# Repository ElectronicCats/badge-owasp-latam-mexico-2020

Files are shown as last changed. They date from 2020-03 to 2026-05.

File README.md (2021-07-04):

# Badge OWASP LATAM México 2020

Una vez mas en el año 2020 nos reunimos para celebrar OWASP Latam México 2020, en Electronic Cats hemos creado un badge electronico para todos los asistentes, bienvenidos a la #badgelive

## Capture The Flag

Unete al reto de Capture The Flag y descubre todo lo que tiene dentro este badge por medio de una herramienta Bluetooth ;)

## Tecnologia

- ESP32 BLE and WIFI
- Convetidor USB-Serial
- LED WS2812B Mini
- OLED
  - [Version 1](https://uelectronics.com/producto/display-pantalla-oled-blanco-128x32-0-91-i2c-ssd1306/)
  - [Version 2](https://articulo.mercadolibre.com.mx/MLM-878713326-display-pantalla-oled-128x32-091-arduino-pic-i2c-lcd-_JM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)

## Links

- [ESP32 con Arduino](https://github.com/espressif/arduino-esp32)
- [Herramienta para carga de binario CTF](https://github.com/espressif/esptool)

## Agradecimientos
¿Quieres dar las gracias? Etiqueta a estas empresas en redes sociales y muestrales tu badge, gracias a ellos es posible

- [PCBWay](https://www.pcbway.com/)
- [LCSC](https://lcsc.com/)
- [ESPRESSIF](https://www.espressif.com/)

## License

Electronic Cats invests time and resources providing this open source design, please support Electronic Cats and open-source hardware by purchasing products from Electronic Cats!

Designed by Electronic Cats.

Hardware released under an CERN Open Hardware Licence v1.2. See the LICENSE_HARDWARE file for more information.

Electronic Cats is a registered trademark, please do not use if you sell these PCBs.

Dec 2019

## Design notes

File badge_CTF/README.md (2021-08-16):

# OWASP Riviera Maya
### (Capture The Flag)

**Instalación en ESP32.**
**Linux**
./esptool.py -b 115200 --port /dev/ttyUSB0 --chip esp32 
   --before default_reset
   --after hard_reset  write_flash --flash_freq 80m 0x000000 ./badge_v1.1.bin

**Windows**
./esptool.py -b 115200 --port COM3 --chip esp32 
   --before default_reset
   --after hard_reset write_flash --flash_freq 80m 0x000000 ./badge_v1.1.bin

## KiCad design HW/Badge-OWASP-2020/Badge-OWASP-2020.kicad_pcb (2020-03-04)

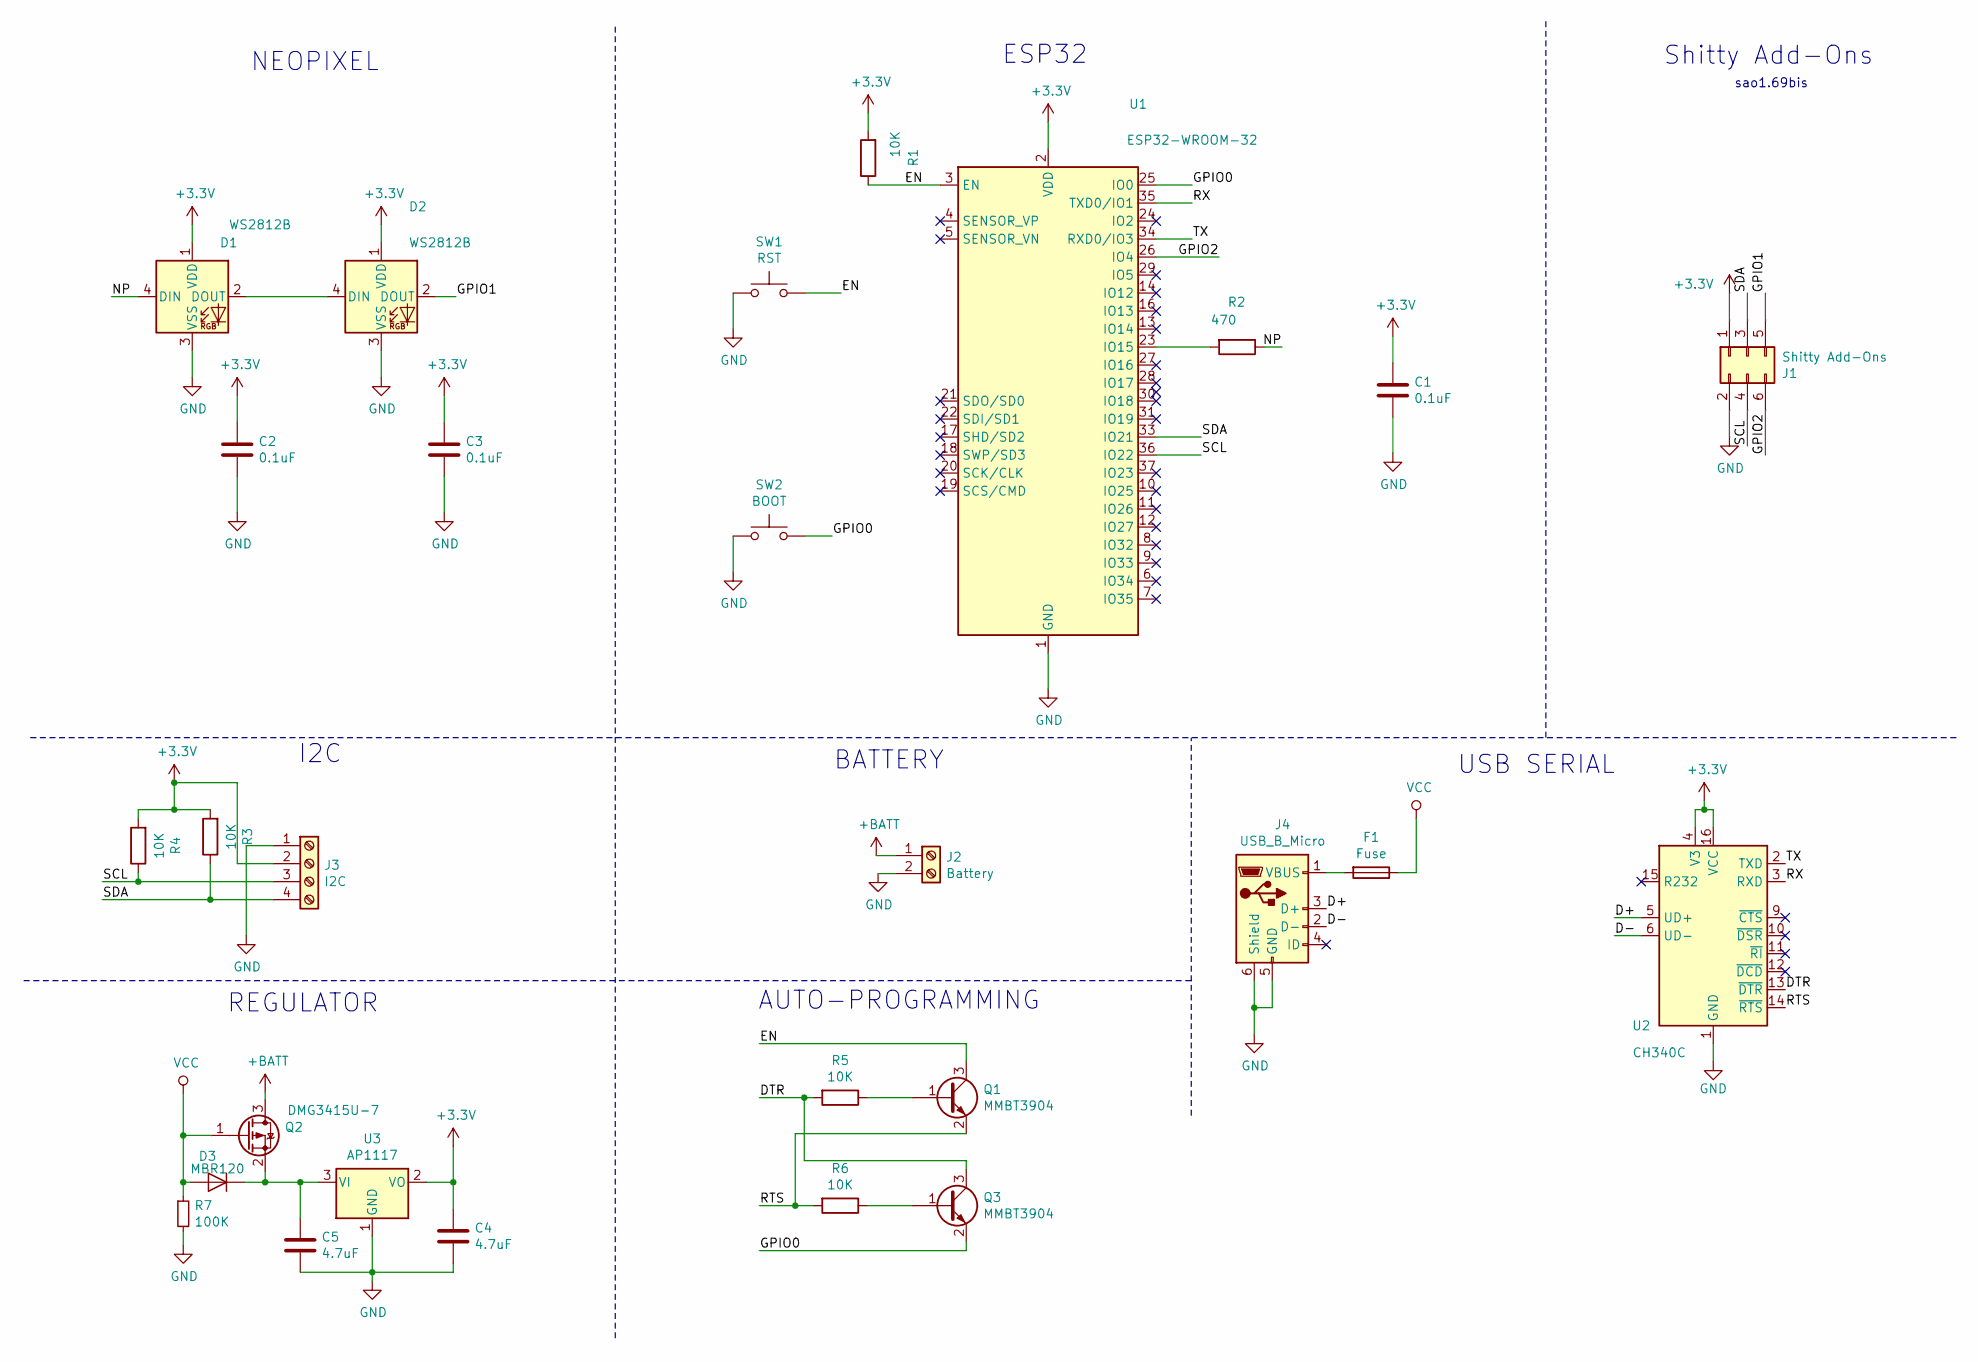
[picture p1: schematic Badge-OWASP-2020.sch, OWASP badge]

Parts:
C1, C2, C3: 0.1uF; C_0805_2012Metric_Pad1.15x1.40mm_HandSolder
C4, C5: 4.7uF; C_0805_2012Metric_Pad1.15x1.40mm_HandSolder
D1, D2: WS2812B; LED_SK6812MINI_PLCC4_3.5x3.5mm_P1.75mm
D3: MBR120; D_SOD-123F
F1: Fuse; Fuse_1812_4532Metric_Pad1.30x3.40mm_HandSolder
J1: Shitty Add-Ons; PinHeader_2x03_P2.54mm_Vertical
J2: Battery; PinHeader_1x02_P2.54mm_Vertical
J3: I2C; PinHeader_1x04_P2.54mm_Vertical
J4: USB_B_Micro; U254051N4BH806
Q1, Q3: MMBT3904; SOT-23
Q2: DMG3415U-7; SOT-23
R1, R3, R4, R5, R6: 10K; R_0805_2012Metric_Pad1.15x1.40mm_HandSolder
R2: 470; R_0805_2012Metric_Pad1.15x1.40mm_HandSolder
R7: 100K; R_0805_2012Metric_Pad1.15x1.40mm_HandSolder
SW1: RST; SW_SPST_TL3342
SW2: BOOT; SW_SPST_TL3342
U1: ESP32-WROOM-32
U2: CH340C; SOIC-16_3.9x9.9mm_P1.27mm
U3: AP1117; SOT-223-3_TabPin2

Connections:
+3V3: C1.1, C2.1, C3.1, C4.1, D1.1 (VDD), D2.1 (VDD), J1.1, J3.2, R1.2, R3.2, R4.2, U1.2 (VDD), U2.4 (V3), U2.16 (VCC), U3.2 (VO)
+BATT: J2.1, Q2.3 (D)
/D+: J4.3 (D+), U2.5 (UD+)
/D-: J4.2 (D-), U2.6 (UD-)
/DTR: Q3.3 (C), R5.2, U2.13 (~DTR)
/EN: Q1.3 (C), R1.1, SW1.2, U1.3 (EN)
/GPIO0: Q3.2 (E), SW2.2, U1.25 (IO0)
/GPIO1: D2.2 (DOUT), J1.5
/GPIO2: J1.6, U1.26 (IO4)
/NP: D1.4 (DIN), R2.1
/RTS: Q1.2 (E), R6.2, U2.14 (~RTS)
/RX: U1.35 (TXD0/IO1), U2.3 (RXD)
/SCL: J1.4, J3.3, R4.1, U1.36 (IO22)
/SDA: J1.3, J3.4, R3.1, U1.33 (IO21)
/TX: U1.34 (RXD0/IO3), U2.2 (TXD)
GND: C1.2, C2.2, C3.2, C4.2, C5.2, D1.3 (VSS), D2.3 (VSS), J1.2, J2.2, J3.1, J4.5 (GND), J4.6 (Shield), R7.2, SW1.1, SW2.1, U1.1 (GND), U1.15 (GND), U1.38 (GND), U2.1 (GND), U3.1 (GND)
unnamed: C5.1, D3.1 (K), Q2.2 (S), U3.3 (VI)
unnamed: D1.2 (DOUT), D2.4 (DIN)
unnamed: F1.2, J4.1 (VBUS)
unnamed: Q1.1 (B), R5.1
unnamed: Q3.1 (B), R6.1
unnamed: R2.2, U1.23 (IO15)
VCC: D3.2 (A), F1.1, Q2.1 (G), R7.1

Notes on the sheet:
NEOPIXEL
ESP32
REGULATOR
USB SERIAL
AUTO-PROGRAMMING
I2C
BATTERY
Shitty Add-Ons
sao1.69bis

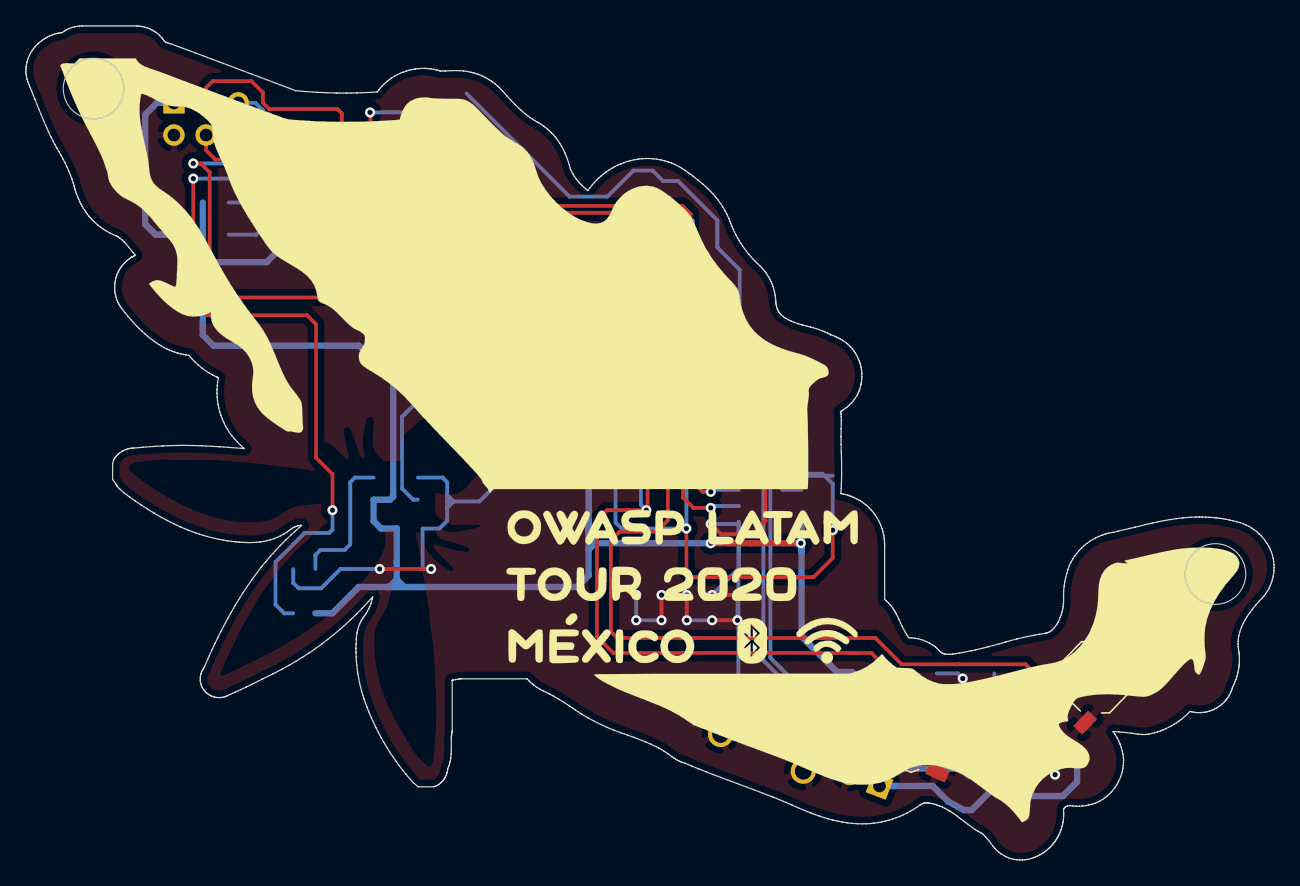
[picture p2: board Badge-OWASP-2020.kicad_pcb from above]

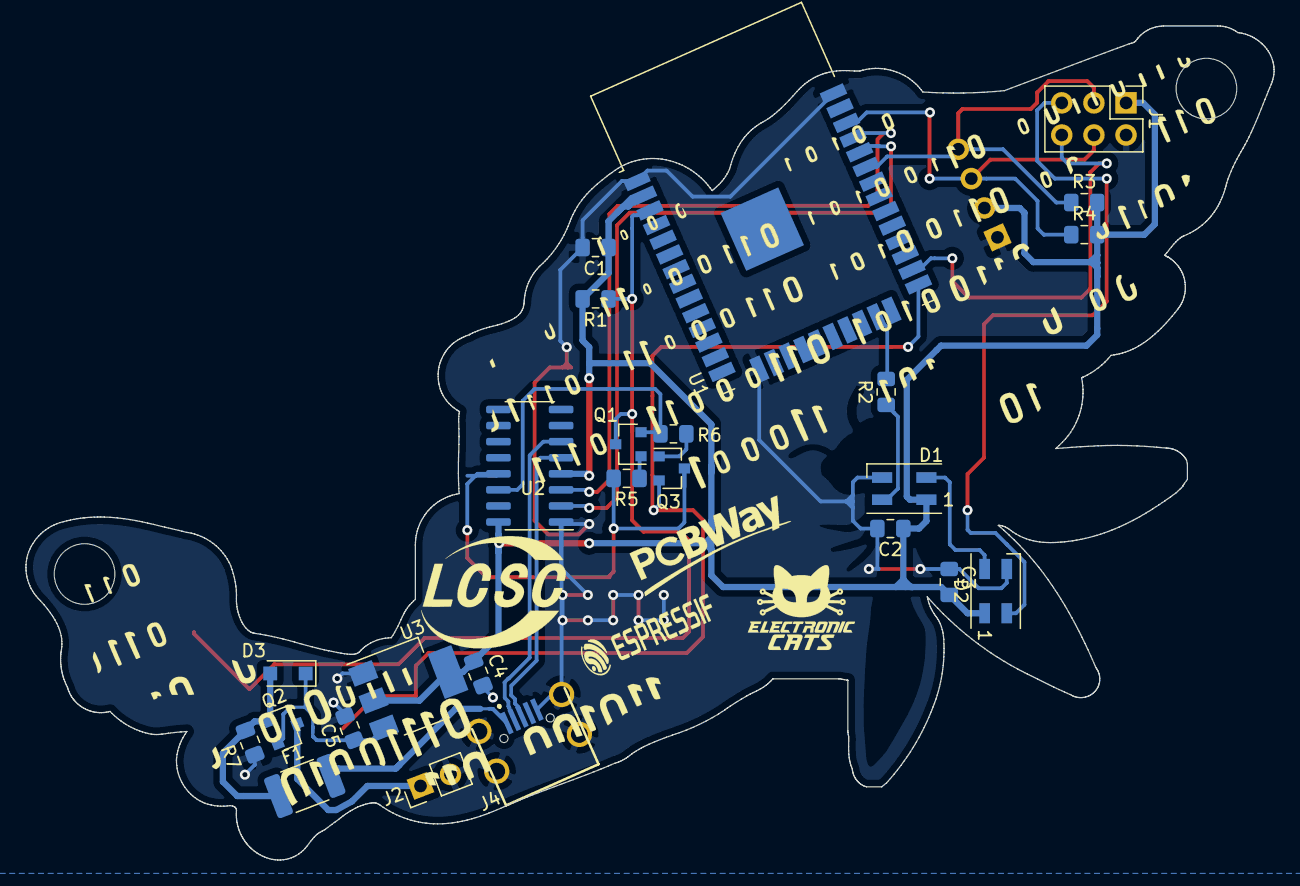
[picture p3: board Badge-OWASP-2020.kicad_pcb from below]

Board: 2 copper layers, 98.6 x 65.9 mm, 29 parts (25 on the bottom side), 23 nets.

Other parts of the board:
Ref**: Val**; Badge_2020_OWASP

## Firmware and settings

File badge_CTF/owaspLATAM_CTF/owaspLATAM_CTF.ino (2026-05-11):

#include <SPI.h>
#include <Wire.h>
#include <WiFi.h>
#include <WiFiClient.h>
#include <WiFiAP.h>

#include <Adafruit_GFX.h>
#include <Adafruit_SPITFT.h>
#include <Adafruit_SPITFT_Macros.h>
#include <gfxfont.h>
#include <Adafruit_GrayOLED.h>
#include <Adafruit_SSD1306.h>
#include <Adafruit_NeoPixel.h>
#ifdef __AVR__
  #include <avr/power.h>
#endif

// NeoPixel
#define PIN 15      // Puerto I0515
#define NUMPIXELS 2 //Número de leds
Adafruit_NeoPixel pixels(NUMPIXELS, PIN, NEO_GRB + NEO_KHZ800);

// Definiciones de pantalla
#define SCREEN_WIDTH 128
#define SCREEN_HEIGHT 32
#define OLED_RESET 4
#define SCREEN_ADDRESS 0x3C
Adafruit_SSD1306 display(SCREEN_WIDTH, SCREEN_HEIGHT, &Wire, OLED_RESET);

// Datos de configuracion del AP
const char *ssid = "Wifi CTF";
const char *password = "yx67SnMw";
WiFiServer server(80);

IPAddress IP = IPAddress(10,20,1,2);
IPAddress MSK = IPAddress(255,255,255,0);
IPAddress GW = IPAddress(10,20,1,1);
int flagWifi = 0;  //Wifi deshabilitado

// Simbolo hacker
static const unsigned char PROGMEM logo[] = {
0x00,0x00,0x00,0x00,0x00,0x00,0x00,0x00,0x1f,0xff,
0xff,0xfc,0x20,0x00,0x00,0x00,0x20,0x03,0xe0,0x00,
0x20,0x07,0xf0,0x00,0x20,0x07,0xf0,0x00,0x20,0x07,
0xf0,0x00,0x20,0x07,0xf0,0x00,0x20,0x07,0xe0,0x00,
0x20,0x01,0xc0,0x00,0x20,0x00,0x00,0x00,0x20,0x00,
0x00,0x00,0x20,0x00,0x01,0xf0,0x20,0x00,0x01,0xf8,
0x20,0x00,0x03,0xf8,0x20,0x00,0x03,0xf8,0x20,0x00,
0x03,0xf8,0x20,0x00,0x01,0xf8,0x20,0x00,0x00,0xf0,
0x20,0x00,0x00,0x00,0x20,0x00,0x00,0x00,0x27,0x81,
0xc0,0xf0,0x2f,0xc7,0xe1,0xf8,0x2f,0xe7,0xf3,0xf8,
0x2f,0xe7,0xf3,0xf8,0x2f,0xe7,0xf3,0xf8,0x2f,0xc7,
0xf3,0xf8,0x27,0xc3,0xe1,0xf0,0x20,0x00,0x00,0x00,
0x00,0x00,0x00,0x00,0x00,0x00,0x00,0x00
};

// Imagen OWASP Riviera Maya en base64
char *img[] = {
              "/9j/4AAQSkZJRgABAQEAWgBaAAD/2wBDAAoHBwgHBgoICAgLCgoLDhgQDg0NDh0VFhEYIx8lJCIf",
              "IiEmKzcvJik0KSEiMEExNDk7Pj4+JS5ESUM8SDc9Pjv/2wBDAQoLCw4NDhwQEBw7KCIoOzs7Ozs7",
              "Ozs7Ozs7Ozs7Ozs7Ozs7Ozs7Ozs7Ozs7Ozs7Ozs7Ozs7Ozs7Ozs7Ozs7Ozv/wgARCABlAGUDAREA",
              "AhEBAxEB/8QAGwAAAwEBAQEBAAAAAAAAAAAABAUGAwIBAAf/xAAUAQEAAAAAAAAAAAAAAAAAAAAA",
              "/9oADAMBAAIQAxAAAAFyKj0JGxPFQLzkUnRyUpNhYGejojCrMR0TIKHDcSnIuGZ0LggJKMlxGPR4",
              "LgU9OQg4ARmFCILBynE5oZigbmBoICtOiZLcJAxUTwYMRGUZKHo2NycL0HIwZBI9Js4ABsDlEcDs",
              "kzA7PggcEgYlSSw3FJeC8YiMBEB+hAQrFoWJhmVQjPTkHBz0biEPDTAajInAQVj8pxOKByTYCPBc",
              "WAjNTIxCzYli8J4CMiqNwkGPjU1OgMZAwMaBR0f/xAAkEAACAgIBBAIDAQAAAAAAAAADBAIFAAEV",
              "ERMUNBI1ISQ2Bv/aAAgBAQABBQJ56Sk+ZP05k+K2hDsuMSWX3dGjgS6KNN2bO1XpnBq6NvOYPnNG",
              "1pY2zr3PtWVkRIy1wY7Mv6RtvtQesSswrkYLxStNHmx61UTs1XOnxljbVFW/X3Ps3CxzsJJMwcl/",
              "R/HYLgK4n7QzryegVqDG2PWroblT+A3hBzF/n636+0VOcvyu+nyusWWd3ZN9zZ61WQ3dtCYYqljL",
              "4vp2aq4LZWHyusMO3YEkOQk7ZkwC1jc5qHuASB37LxZQO9TVZT6cBV9WuRb1ONupOT78For2Z9HA",
              "eDAcOuM8VEDARLVMAFWLHNA5vnJpqIYVwm9Y8dUs0TAjCNW5NhuCncKRtGaE5ERfeirirBds3BJa",
              "dqVjbxxTvjrg65Sxse5pRoIJU4omX+DCliRoMbKVfudlGOo6uevk20uzYbsfOzhd48Px6dDX6Vk5",
              "5GJJ7bm63oEjClXu83+esrKwWF2F3lRHL5AMbUWbPqnWntkGl2EPRXAuqzwwJ7r6+DYyVAYLrr90",
              "jJJBVrfr7rXVglVXhyFdWykBeKt7YKsTehasrQjUAYgIzNdOoIGC/wCktXISWlV+OpxasBjWuPZv",
              "faQ96X9GUwwQ3WJtbO2+nqUVLPRUxklBWcW2kUx4TTwkK36+6/DLDNS1IZKcRBmGxfynJq1iUqBn",
              "GyNbXVCuOn38E4NiKJQ02LS4+trfrzLBPvjU841PBpLCnpcOjmAM8eNTzp+BqgDDjU8giqOZBQNC",
              "EIih/8QAFBEBAAAAAAAAAAAAAAAAAAAAcP/aAAgBAwEBPwEp/8QAFBEBAAAAAAAAAAAAAAAAAAAA",
              "cP/aAAgBAgEBPwEp/8QAOxAAAQMDAgMFBQUGBwAAAAAAAQACAxESMQQhEyJBFDJCUXEjMzRhcgVS",
              "oaLCEIGR0eHwFSRDYpKx8f/aAAgBAQAGPwKNrYr7/wAF8GV8GUyF2nsu61wuI2O81wvhPxTXVFSK",
              "kVwpbobLMfNSyOhs4fTzW2j/ABXwZwqnRn+KZKW23DC0vqmsYxrqtruo4jGwB5TfT9KIgtlmH+nk",
              "/wAFwZYg2012yuM1ziZWioKkE5jit7u9KqX6Cp5GjuuJ39EPZR4RmeKFxwPqUPotNjKYYoS8Bqhc",
              "7TkAHcpuMfpUmplbZD98+inDjyGrgWlWcNrWNNrC4ZCJZI5zhu6hwpfoK1LWtqSTQD0Q/wAs7Cse",
              "y1wOD9Sh9FC6GO63O+F3B+Vd0flUeo1EX1OqPJPGs20XQ/3unzMZ7BzeR1cqWP7Qf7ONxsoP5Kcv",
              "jtvpbvnKmbqm85FG4VkUQaCa5au6Mf7UY5YwWnpVqjY8WuA3ChEUtl2fmpZZ5L7DmnSicIXuEhHK",
              "bV2ntHsxkplCHyO3qfVO00klRGzu+WFM7Uxtcxxq3dU7TsD5JoBdzGg5U6K4tlLKt2UZm1FY/EKI",
              "Sx90/s5mNc4DlJ6KeB5ZdJWlMYRlc6KjW70/8UbnPadNvWPz/cj9n6OsUreuAuHHVmraaSSjxIyT",
              "zXse2rRXCZ2aLh0Juq0bosljukeaRup3SmP1EscgB3qa7LsUUAbO4crrdgjp+ORZ9w7KJzzcSMpr",
              "C0kyA0I6KAGeU1kHVWcR4bw8DCi1AnPCFeRHhERynx9VLFL7Utaa3CvkuFFfFwnU5VJxYuLdiowp",
              "sF3hc4YUEUmpe+4g5PmmQGGsh8dEdS5zXRnwEfJUaAB5BaalcqB7W7NANB13XZ+BwzLtfWtq+N/L",
              "/VCISXlpyFCab2BGNsNnDfkdVJWbh2HyymwNjrxtrgcKL2hmpz+SB7JvT739FkwiQetEyO++0ZUT",
              "pJuHZj5r30f/ACXFOqa3lpSoQa3WVPyopIhc63qofoCll7S0l53BI2TnM1V1N9qJznOdHwynyx6g",
              "yWA4TA4OYw7F/QJ2iYwyQtxKOvVQ+i0wQbJqXM67uCDW6sknYC8KOJhJDR19FO5sD3A4IHohBw4+",
              "QU5sriufIDLzmhCf7GnFPjCmjlkay/bcqeGHUtfcCd3DyR080zWXE+LdcHj+w+/cPNMbE65gGxWm",
              "2GVHsO51Kg2bnzTdhj9Kvlda3zRn5jxN6gq21rYwbWV8kKvuMWben90Tf8PaZWDvGuFFDPFZefPo",
              "jFESdRTlZXK4MkIbCP5qH0WmJQfMS4jYbOTXsqHN3HeTJYzVpH6U/RzG6DNqd2g26McsfX0Tg+QO",
              "Y1/LsnOibQvHNutS5p3G/wCCdNqX11bPdGigkldc5Sfu/wC1D6IGWMOtwvcNXuGoPZCGuGCjOGDi",
              "HxK2VgcMr3DVROZHGGtdkL3DUHshAc3BVkjbmnogxgo0YC//xAAlEAACAgICAQUBAQEBAAAAAAAB",
              "EQAhMWFBUXGBobHR8JHBEPH/2gAIAQEAAT8hz8JlqKx5uz9QEXQTk/US5O2YAnrUNjhAFmeMDZfU",
              "DhFBa0Fp67E99ahv5gwRPB9QeyHwX1MXIRyfqFYFcl9RzAw9ItgOXOxASJwv3Fi4EhsRMRe20O8g",
              "KGjwuUbaYYAVi/MFDAkEHccPoDdzs6n7PUK3CKHJDPKCPO96gqIB6UnG/XAdeTJXIixiSRxZlj7x",
              "xmBcvUvKF+QFxYRtLICbH3CTpog9fERnkAbfyfo9QWQNIbKweZRjzucpwVKNLx8wTkXZBkOzKWR/",
              "uYKXiPr/ALB1ggeAsBQPiGKbQhNqsdooqaOMYVN4EoUUwEWR7IeDCw0PubEFqYCMq1DAohBlrZmH",
              "uPf+xFVGhzoyr+TGonAZE8hqK/jEhgDQw5LMI9YYkDLWFAqUGoBRQU4uFGQIdQxuKjbWpV0RA6/y",
              "PD/II6ERQwGV8QuC4gzzqGUJamFgr/l+wI5QhGID7kuob0OTKClmhybX0WVAMysYIybF89RH1NVt",
              "eTahlPTElrgyaegcF/sosKh8n9UGOdcI9LEc4Ep3Zz3xKDkKJlf+wx21LJuLVkI/OYJiBEErsbiM",
              "IWNbO5gUEkTeRjEI1YCoSeRcJKgGoCQbXAZDTJJ5HHiA8hGAp37gfIaViayJifGCiKIs6gI4YSqo",
              "+sCWC2OkBxVgCAnRjNeRCG8lNdIrGsv/AMglAAVCBiaF4ibgeasKuGIgZQTPmOo/lA21nvUDHQTS",
              "vTxuHRBaZXjnqKeTC5Pz6cEHp1GLgN4HeRMCRyHc/wDIx/5hG73uDgKoMJ94MYAAbYlK12QWiMlZ",
              "OAshEwcoAONu3+UZcEkLKxEewSNuaik4HYejJUpQR1PmP7knnYhgnGgHJ9oF0yDT7QsQiJh2ZiU1",
              "sSDAfCUoFPNwdWIKAJuq3BbShmDTxjuMtlEgmuJaYHAok048SxWwIE/CVOT7xnGZyD8253y2TsTs",
              "PgcncHjtfLc+UHeUUaApo+vWkFwstGiLDHPSh9MC2JjBpIu49oNIiCM2K7gfJfc34w+75d2y+50A",
              "NfMMEgon5ECJBiPiZpweEYbJFEchBrQUVWADkXM2cCALeF4BzDzALVC9RPGzYXW/MOGBSPRaXxYk",
              "gAgxQrLzA2S00u57j4p+3cLoch4la+afBczD+kdQKFk5QHGZQHuZObzEwUkpiADcz9xmNRg6huJk",
              "FB0RUDif/9oADAMBAAIAAwAAABAAQAACCAACCAAACQCCASQSQCAQCCCCQQQQASCCCACCAQCAACCA",
              "AAAACASQCAAQQSACAQCSCCAQAAAQCCCSQCQf/8QAFBEBAAAAAAAAAAAAAAAAAAAAcP/aAAgBAwEB",
              "PxAp/8QAFBEBAAAAAAAAAAAAAAAAAAAAcP/aAAgBAgEBPxAp/8QAJBABAAICAgICAwEBAQAAAAAA",
              "AREhADFBUWGRcYGhscHw0RD/2gAIAQEAAT8QjXtxoQ4Hv8YhZ1Ea4j+8Skc9TSa9fzj9iNEYBSNw",
              "94ApiiKLuhy8jgyElJj/AHjD9R5JAUeaWMCF3EW8x073i926YrkOoyFCu02E5H74caTXr+cSBSUh",
              "NxnY+4zukTB1iMsaIhH15vfmgMiKTrNVoyyXUvjHH8lp8Uf3D2KmMraroQ4QhMAShRKIlUTWan5U",
              "EUgOXB20MFND3RDXecj/AA8MOsuRJuIrBvpbxwGPwQgUImeshWQ1FnliLkjkx12TkJStsKaNneBm",
              "+iYM+XnE+1PxU/zJOoCYagG+xNcYsQR8aduaTp1i0pWV8GYSwe2JHSAyyx9h9Z4Xk+eWZmbIQ239",
              "4DqKtS6ex7yurJ+yRKvSO8EBA6qTbnH/ACpZqQoJ096xqrab0qP2yT2dfZH6Y+eCH9zAUc4ATwiL",
              "t5OMCzH9VXmoPIGsOtEKFMUS05yA6ARRKaUeSN4EKuxsyJcbjeWHeJYiZV4MNnzjsj9MMT6CQgSw",
              "eMPbDkSSsSKPvOFdtog2o29bxe0RggIACecTjAhCOWZ6eMPNrF+27Q1hJiwAQcgaDjBbkQRTCCdv",
              "PODDt4WVotHbnFQ9JVBiPrixRZkCkP6ZZ5dUMEt8rjCbIGJJwr0cmsszWzLFXyP/AIoTpkZCkeLD",
              "1jKBwYU9HPhrH/8AslUzoR2c94+9IrAwdjdvicXkwODSIRt7MAAkQpErYGSwmMJI7VcCRAGGKXIF",
              "6JgrRCzEdN5qYqOgAmRLKQdYN7wHVlPytSbxZP5CySpkijRbyQWVFFjUg+VbnJotnyktuAjcCJUS",
              "+nrEMMnBa3rf5cjBUqeSkCa64MnAoC57rOyP1gi2SWDY8wg3kQIAhUmTe7ibck2kJokACIMOueGz",
              "GSSdyajWDdIAKnCWkMNdYN5qoMX2BxziscGVKm06PvApUFpQTI1snAvHAAPAaylUkCUJz4eSCIJW",
              "FCpiJhwG3AJCzcXa7N48eRSu1/bBzGu4t1K8xvCqFh2Vy7yR9bFzIBGp27xXDOGElCkR8t4X7EQN",
              "XApi2zWDg6yEQXf7fOskRqk7ETU/D855SUWD/afjvHkxqY3WYl77xs/h3c5HRrvKJ/0/OFA2pEcr",
              "8nrJfBDtgsB8vWHZ/wBTn1D/AIwQpQo2Ky8bJBWjfdXiWkGSrQYa59YClFAAgqrEBgRpCpBKwsOv",
              "eGd1tR3IPabMuuNKElAg0T6YIVHzC2FWALQb78MMSKRqb1rET8VJZ0F23JDXInLTAcvWa2VXE0Q8",
              "PrB0cYKASCNz4ME+URLUSdS9rxeQBHUQVry772YRNGBBY25vLMCAKIEDpk54UCSGSZ7cd4olQkXJ",
              "8XwaxesUphluQB+sM+UEaddk/nDPy3+hMg4huVL0NsFv+Son+YqAxApLrWGQDuNhIRWJnlh7FtmG",
              "IXLBKmZku/wx3KFErpG+h05rNFJyiW6fWUtIebFeA08sgUetSFFy7ZTmGlIW5wJAczP48eNEkEGY",
              "iHeX1VBdJVhp53hiZxMYVSdjhG1gygRiNl5yKAqwEhFHvftcYpA5hOgaC0G5xnbIZ8SbMba7w6hI",
              "hYEGHNPCFkJQHDVHzWTZNRvAJQBgGZA5pj6MhWidflkj6rsziYh8GUqYyE/9YDEHAi9HfPlw2Voi",
              "UhGL6X3hgagpkQHcaDA6Pk4AINeF94qBcUt2fflwMkR+h1gCYiTBiLvpwHR75/6zc3iS31flxz/D",
              "Jhhk15M4xyAGf//ZVzJac1lXY3lPaUEyTlRjNFhRcGhXRUZuU1VOQloxUllWbXhqTTFKNVdWTkNh",
              "MkZZU214Wk1rNXdZakkwWjJGWVFVdGFiV3h6V2xOQgpaMUV5Um5sYU1rVm5XVmhLYW1GSGJESmll",
              "VFJMV1RKNGJGbFlTV2RWYlZad0NtSnRiR3BoVjBaNVNVVk9WVkpwTkV0amJsWjFTVU5CCloxTlhO",
              "WEJaTW14b1NVaE9iR051V25CWk1teDJUR2R2UFFvPQo="
};
// control de las etapas de cada uno de los eventos.
int stage = 0;    //0: Flag 1, 1: Flag 2 y 2: flag 3
bool pantalla = false;

String cmd = "";

void setup() {
  // Iniciando pixels
  pixels.begin();

  // Iniciando OLED
  if(!display.begin(SSD1306_SWITCHCAPVCC, SCREEN_ADDRESS)){
    Serial.println(F("SSD1306 allocation failed"));
    pantalla = false;
  }else{
    intro();
    pantallaOLED("Asistente\n  0xFF", 2, true);
    delay(1000);
    pantalla = true;
  }
  
  // Velocidad de comunicación:
  Serial.begin(115200);
  cmd.reserve(10);

  introSerial();

}

void loop() {
  char letra;
  bool error = false;
  WiFiClient cliente;

  pixels.clear();
  pixels.setPixelColor(0, pixels.Color(0,250,0));
  pixels.show();
  delay(100);
  
  // put your main code here, to run repeatedly:
  if (Serial.available() > 0){
    letra = (char)Serial.read();

    if(letra != 8){
      cmd += letra; 
    }

    if(letra == '\n' || letra == '\r') {
      cmd.trim();
      error = instrucciones(cmd);
      cmd = "";
    }else if( letra == 8 && cmd.length() > 0){
      cmd.setCharAt((cmd.length() - 1), ' ');
      cmd.trim();
    }
    if(error) {
      pantallaOLED("Error", 2, true);
      correcto(error);
      error = false;
    }
  }

  switch(flagWifi) {
    // Carga configuración AP
    case 0:
      WiFi.softAP(ssid, password);
      WiFi.softAPConfig(IP, GW, MSK);
      server.begin();
      flagWifi = 1;
      Serial.println("Servicio iniciado...");
      delay(1000);
    break;

    // Inicializa el servicio
    case 1:
      cliente = server.available();
      if(servicioWeb(cliente)){
        if(pantalla) {
          pantallaOLED("Felicidades",2, true);
        }else {
          Serial.println(F("Felicidades!!"));
        }
        flagWifi = 2;
      }
    break;

    default:
    break;
  }
  pixels.clear();
  pixels.setPixelColor(1, pixels.Color(0,0,250));
  pixels.show();
  delay(100);
}

bool instrucciones(String instr){
  // Instrucción no valida.
  bool error = false;

  //Se escogio visualizar archivo.
  if(instr.equals("file") && stage == 1){
    Serial.println("> Looading....");
    for(int i = 0; i < 85; i++) {
      Serial.println(F(img[i]));
    }
    //Se habilita escenario de habilitar inalámbrico
    stage = 2;
  //Se escogio mostrar llave.
  }else if(instr.equals("help") && stage == 0){
    if(pantalla){
      pantallaOLED("[flag1]\n 9601",2, false);
    }else{
      Serial.println(F("[flag1]: 9601"));
    }
    
    correcto(false);
    Serial.println(F("[flag1: 9601]"));
    Serial.println(F("help:"));
    Serial.println(F("file--------> Cargar archivo"));
    Serial.println(F("XXX--------> XXXXXXXXXXXXXX"));
    Serial.println(F("XXX--------> XXXXXXXXXXXXXX"));
    Serial.println(F("XXX--------> XXXXXXXXXXXXXX"));

    if(pantalla){
      pantallaOLED("Stage 1\nCompleto!",2, true);
    }else {
      Serial.println(F("Stage 1\nCompleto!"));
    }
    
    //Se habilita escenario de mostrar archivo.
    stage = 1;
  //Se escogio mostrar mensaje
  }else if(instr.equals("ip") && stage == 3){
    //Serial.println(WiFi.softAPIP());
    if(pantalla){
      pantallaOLED("Stage 2\nCompleto", 2, true);
      pantallaOLED("IP:\n 10.20.1.2",2, false);  
    }else{
      Serial.println(F("Stage 2\nCompleto"));
      Serial.println(F("IP: 10.20.1.2"));
    }
    correcto(false);
    
    stage = 2;
  //Limpiar pantalla
  }else if(instr.equals("clear")){
    if(pantalla){
      pantallaOLED("Hack me!!\nIf you can", 2, true);
    }else{
      Serial.println(F("Hack me!!\nIf you can"));
    }
    
    stage = 0;
  // Comando incorrecto
  }else if(instr.equals("run") && stage == 2){
    flagWifi = 0;
    Serial.println("\nLNTGYYLHGM5CAMZVGQ4V2CSXNFTGSICDKRDDU6LYGY3VG3SNO4FA====");
    if(pantalla){
     pantallaOLED("Service on",2, false); 
    }else {
      Serial.println(F("Service on"));
    }
    
    correcto(false);
    //Se habilita escenario para mostrar IP del Badge
    stage = 3;
  }else {
    Serial.println(F("Error"));
    cmd = "";
    error = true;
  }

  return error;
}

boolean servicioWeb(WiFiClient cliente){
  boolean ganador = false;

  if(cliente) {
    String lineaCaptura = "";
    String tmp = "";
    while(cliente.connected()){
      if(cliente.available()) {
        char c = cliente.read();
        Serial.write(c);
        if(c == '\n') {
          if(lineaCaptura.length() == 0){
            cliente.println("HTTP/1.1 200 OK");
            cliente.println("Content-type:text/html");
            cliente.println();

            // Cuerpo de la pagina
            cliente.print("<html><head><title>CTF</title></head><body><h1>Validar banderas</h1>");
            cliente.print("<p>Para validar las banderas, escribe lo siguiente en la url: http://10.20.1.2/?flag1=valor1&flag2=valor2&flag3=valor3</p>");
            cliente.print("<p>Donde valor1, valor2 y valor3 son los códigos de las banderas encontradas</p>");
            cliente.print("</body></html>");

            // Termina un salto de línea
            cliente.println();
            break;
          }else{
            lineaCaptura= "";
          }
        } else if(c != '\r'){
          lineaCaptura += c;
          tmp += c;
        }
      }
    }
    if(tmp.indexOf("flag1") >= 0 || tmp.indexOf("flag2") >= 0 && tmp.indexOf("flag3") >= 0){
      ganador = stageFinal(tmp);
    }
    cliente.stop();
    Serial.println("Cliente desconectado.");
  }
  return ganador;
}

bool stageFinal(String url){
  bool ganador = false;
  int i = 0;
  String flag1, flag2, flag3;

  if(url.indexOf("9601") < 0 || url.indexOf("6578") < 0 || url.indexOf("3549") < 0){
    ganador = false; //Falta uno o varios flags
  }else {
    ganador = true; //Todos los flags encontrados
  }

  return ganador;
}

void pantallaOLED(String msg, int sizef, boolean scroll ){
  display.stopscroll();          // detener siempre primero
  display.clearDisplay();
  display.setTextSize(sizef);
  display.setTextColor(SSD1306_WHITE);
  display.setCursor(0,0);
  display.println(msg);
  display.display();

  if(scroll){
    display.startscrollleft(0x00, 0x03);
  }
}

void correcto(boolean f) {  
  pixels.clear();
  for(int i = 0; i < 5; i++){
    if(f) {
      pixels.clear();
      pixels.setPixelColor(0, pixels.Color(250, 0, 0)); 
      pixels.show();
      delay(500);
      
      pixels.clear();
      pixels.setPixelColor(1, pixels.Color(250, 0, 0));
      pixels.show();
      delay(500);
    }else{
      pixels.clear();
      pixels.setPixelColor(0, pixels.Color(0, 250, 0));
      pixels.show();
      delay(500);

      pixels.clear();
      pixels.setPixelColor(1, pixels.Color(0, 250, 0));
      pixels.show();
      delay(500);
    }
  }
}

void introSerial(){
  Serial.println(F("\n\n##############################"));
  Serial.println(F("# SHALL WE PLAY TO BE HACKER #"));
  Serial.println(F("#  by Darkwolf und Glitchboi #"));
  Serial.println(F("##############################\n"));
}

void intro(void){
  display.clearDisplay();
  display.drawBitmap(48,0,logo,32,32, 1);
  display.display();
  delay(3000);
}

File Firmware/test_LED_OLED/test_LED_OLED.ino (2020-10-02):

/********************************************************************
This is an example for our Monochrome OLEDs based on SSD1306 drivers
  Pick one up today in the adafruit shop!
  ------> http://www.adafruit.com/category/63_98
This example is for a 64x48 size display using I2C to communicate
3 pins are required to interface (2 I2C and one reset)
Adafruit invests time and resources providing this open source code,
please support Adafruit and open-source hardware by purchasing
products from Adafruit!
Written by Limor Fried/Ladyada  for Adafruit Industries.
BSD license, check license.txt for more information
All text above, and the splash screen must be included in any redistribution
*********************************************************************/
#define OLED

#ifdef OLED
#include <SPI.h>
#include <Wire.h>
#include <Adafruit_GFX.h>
#include <Adafruit_SSD1306.h>
#endif
#include <Adafruit_NeoPixel.h>

#define SCREEN_WIDTH 128 // OLED display width, in pixels
#define SCREEN_HEIGHT 32 // OLED display height, in pixels


#define PIN 15

// How many NeoPixels are attached to the Arduino?
#define NUMPIXELS 2 // Popular NeoPixel ring size

// When setting up the NeoPixel library, we tell it how many pixels,
// and which pin to use to send signals. Note that for older NeoPixel
// strips you might need to change the third parameter -- see the
// strandtest example for more information on possible values.
Adafruit_NeoPixel strip(NUMPIXELS, PIN, NEO_GRB + NEO_KHZ800);

#define DELAYVAL 500 // Time (in milliseconds) to pause between pixels

#ifdef OLED
// SCL GPIO5
// SDA GPIO4
#define OLED_RESET -1  // GPIO0
Adafruit_SSD1306 display(SCREEN_WIDTH, SCREEN_HEIGHT, &Wire, OLED_RESET);

#define NUMFLAKES 10
#define XPOS 0
#define YPOS 1
#define DELTAY 2


#define LOGO16_GLCD_HEIGHT 16
#define LOGO16_GLCD_WIDTH  16
static const unsigned char PROGMEM logo16_glcd_bmp[] =
{ B00000000, B11000000,
  B00000001, B11000000,
  B00000001, B11000000,
  B00000011, B11100000,
  B11110011, B11100000,
  B11111110, B11111000,
  B01111110, B11111111,
  B00110011, B10011111,
  B00011111, B11111100,
  B00001101, B01110000,
  B00011011, B10100000,
  B00111111, B11100000,
  B00111111, B11110000,
  B01111100, B11110000,
  B01110000, B01110000,
  B00000000, B00110000 };


#endif
void setup()   {
  Serial.begin(9600);

  strip.begin();
  strip.setBrightness(50);
  strip.show(); // Initialize all pixels to 'off'

  #ifdef OLED
  // by default, we'll generate the high voltage from the 3.3v line internally! (neat!)
  display.begin(SSD1306_SWITCHCAPVCC, 0x3C);  // initialize with the I2C addr 0x3C (for the 64x48)
  // init done

  // Show image buffer on the display hardware.
  // Since the buffer is intialized with an Adafruit splashscreen
  // internally, this will display the splashscreen.
  display.display();
  delay(2000);

  // Clear the buffer.
  display.clearDisplay();

  // draw a single pixel
  display.drawPixel(10, 10, WHITE);
  // Show the display buffer on the hardware.
  // NOTE: You _must_ call display after making any drawing commands
  // to make them visible on the display hardware!
  display.display();
  delay(2000);
  display.clearDisplay();


  // draw the first ~12 characters in the font
  testdrawchar();
  display.display();
  delay(2000);
  display.clearDisplay();

  // draw scrolling text
  testscrolltext();
  delay(2000);
  display.clearDisplay();

  // text display tests
  display.setTextSize(1);
  display.setTextColor(WHITE);
  display.setCursor(0,0);
  display.println("OWASP 2020!");
  display.setTextColor(BLACK, WHITE); // 'inverted' text
  display.println(3.141592);
  display.setTextSize(2);
  display.setTextColor(WHITE);
  display.println("OWASP 2020!");
  display.display();
  delay(2000);
  display.clearDisplay();
  #endif

}


void loop() {
    // Some example procedures showing how to display to the pixels:
  colorWipe(strip.Color(255, 0, 0), 50); // Red
  colorWipe(strip.Color(0, 255, 0), 50); // Green
  colorWipe(strip.Color(0, 0, 255), 50); // Blue
//colorWipe(strip.Color(0, 0, 0, 255), 50); // White RGBW
  // Send a theater pixel chase in...
  theaterChase(strip.Color(127, 127, 127), 50); // White
  theaterChase(strip.Color(127, 0, 0), 50); // Red
  theaterChase(strip.Color(0, 0, 127), 50); // Blue

  rainbow(20);
  rainbowCycle(20);
  theaterChaseRainbow(50);

}

#ifdef OLED
void testdrawbitmap(const uint8_t *bitmap, uint8_t w, uint8_t h) {
  uint8_t icons[NUMFLAKES][3];

  // initialize
  for (uint8_t f=0; f< NUMFLAKES; f++) {
    icons[f][XPOS] = random(display.width());
    icons[f][YPOS] = 0;
    icons[f][DELTAY] = random(5) + 1;

    Serial.print("x: ");
    Serial.print(icons[f][XPOS], DEC);
    Serial.print(" y: ");
    Serial.print(icons[f][YPOS], DEC);
    Serial.print(" dy: ");
    Serial.println(icons[f][DELTAY], DEC);
  }

  while (1) {
    // draw each icon
    for (uint8_t f=0; f< NUMFLAKES; f++) {
      display.drawBitmap(icons[f][XPOS], icons[f][YPOS], bitmap, w, h, WHITE);
    }
    display.display();
    delay(200);

    // then erase it + move it
    for (uint8_t f=0; f< NUMFLAKES; f++) {
      display.drawBitmap(icons[f][XPOS], icons[f][YPOS], bitmap, w, h, BLACK);
      // move it
      icons[f][YPOS] += icons[f][DELTAY];
      // if its gone, reinit
      if (icons[f][YPOS] > display.height()) {
        icons[f][XPOS] = random(display.width());
        icons[f][YPOS] = 0;
        icons[f][DELTAY] = random(5) + 1;
      }
    }
   }
}


void testdrawchar(void) {
  display.setTextSize(1);
  display.setTextColor(WHITE);
  display.setCursor(0,0);

  for (uint8_t i=0; i < 168; i++) {
    if (i == '\n') continue;
    display.write(i);
    if ((i > 0) && (i % 21 == 0))
      display.println();
  }
  display.display();
  delay(1);
}

void testdrawcircle(void) {
  for (int16_t i=0; i<display.height(); i+=2) {
    display.drawCircle(display.width()/2, display.height()/2, i, WHITE);
    display.display();
    delay(1);
  }
}

void testfillrect(void) {
  uint8_t color = 1;
  for (int16_t i=0; i<display.height()/2; i+=3) {
    // alternate colors
    display.fillRect(i, i, display.width()-i*2, display.height()-i*2, color%2);
    display.display();
    delay(1);
    color++;
  }
}

void testdrawtriangle(void) {
  for (int16_t i=0; i<min(display.width(),display.height())/2; i+=5) {
    display.drawTriangle(display.width()/2, display.height()/2-i,
                     display.width()/2-i, display.height()/2+i,
                     display.width()/2+i, display.height()/2+i, WHITE);
    display.display();
    delay(1);
  }
}

void testfilltriangle(void) {
  uint8_t color = WHITE;
  for (int16_t i=min(display.width(),display.height())/2; i>0; i-=5) {
    display.fillTriangle(display.width()/2, display.height()/2-i,
                     display.width()/2-i, display.height()/2+i,
                     display.width()/2+i, display.height()/2+i, WHITE);
    if (color == WHITE) color = BLACK;
    else color = WHITE;
    display.display();
    delay(1);
  }
}
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

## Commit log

2019-12-12 CH340C and AP111733
    [Badge-OWASP-2020.kicad_pcb, Badge-OWASP-2020.sch]
2019-12-12 Add MMBT3904
    [Badge-OWASP-2020.sch]
2019-12-13 Change RTS
    [Badge-OWASP-2020.sch]
2019-12-13 C and GND WS2812B
    [Badge-OWASP-2020.sch]
2019-12-13 Values C and R
    [Badge-OWASP-2020.sch]
2019-12-13 Screen OLED
    [Badge-OWASP-2020.sch]
2019-12-20 Change footprints and add R
    [Badge-OWASP-2020.sch]
2019-12-20 add labels and fix voltage
    [Badge-OWASP-2020.kicad_pcb, Badge-OWASP-2020.sch]
2019-12-24 add battery and protection
    [Badge-OWASP-2020.sch]
2019-12-24 Update labels
    [Badge-OWASP-2020.sch]
2019-12-27 fix GPIO1 for shitty adons with neopixel
    [Badge-OWASP-2020.sch]
2019-12-27 correct pinout sao1.69bis
    [Badge-OWASP-2020.sch]
2020-01-02 Add manf#
    [Badge-OWASP-2020.sch]
2020-01-06 fix names tx and rx drc
    [Badge-OWASP-2020.sch]
2020-01-08 define design :D
    [Badge-OWASP-2020.kicad_pcb]
2020-01-10 component distribution
    [Badge-OWASP-2020.kicad_pcb]
2020-01-10 countour circle
    [Badge-OWASP-2020.kicad_pcb]
2020-01-10 logos space
    [Badge-OWASP-2020.kicad_pcb]
2020-01-10 add logos
    [Badge-OWASP-2020.kicad_pcb]
2020-01-10 fix logos
    [Badge-OWASP-2020.kicad_pcb]
2020-01-10 Add USB connector from LCSC change angle of components
    [Badge-OWASP-2020.kicad_pcb, Badge-OWASP-2020.sch]
2020-01-12 routeo gnd
    [Badge-OWASP-2020.kicad_pcb]
2020-01-12 Update traces and ground plane
    [Badge-OWASP-2020.kicad_pcb]
2020-01-12 add keepout areas :D
    [Badge-OWASP-2020.kicad_pcb]
2020-01-12 add config pcb gerbers
    [Badge-OWASP-2020.kicad_pcb]
2020-01-29 Update buttons
    [Badge-OWASP-2020.kicad_pcb]
2020-03-04 PCB v1.0
    [Badge-OWASP-2020.kicad_pcb]
2021-07-09 Agregando el README y binario del CTF para el badge
2021-07-14 Se corrgio el valor de la primera bandera
2021-07-17 Se corrigio el password de la red WiFi
2021-08-16 Update README.md
    Error de capitalizacion en `write_Flash`. La leta `F` tiene que ir en minusculas.
2021-08-16 Update README.md
    Se modifico el `write_Flash` de linux. La letra `F` debe ir en minusculas
2026-05-11 Fix: Correccion a logos / funcionalidad
    [owaspLATAM_CTF.ino]
2026-05-11 Fix: Correcion de inicializacion
    [owaspLATAM_CTF.ino]
